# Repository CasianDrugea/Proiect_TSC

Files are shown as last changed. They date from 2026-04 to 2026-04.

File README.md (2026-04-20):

# Documentație Tehnică - InkTime Smartwatch
## Student: Drugea Casian 332CA

## 1. Descrierea Generală a Sistemului
Proiectul **InkTime** este un dispozitiv purtabil bazat pe microcontrolerul **nRF52840**, proiectat pentru a oferi o autonomie ridicată prin utilizarea unui ecran de tip E-Paper. Sistemul integrează funcționalități de monitorizare a mișcării, interfață haptică și un management avansat al energiei, fiind optimizat pentru dimensiuni reduse și eficiență.

## 2. Diagrama Bloc
Arhitectura hardware este structurată în jurul nucleului ARM Cortex-M4F, interconectat cu următoarele module:

* **Sistem de Procesare:** nRF52840 (Bluetooth 5.0, GPIO, SPI, I2C).
* **Afișaj:** E-Paper Display (EPD) cu circuit de drive integrat.
* **Senzori & Haptics:** Accelerometru BMA423 și Driver Haptic DRV2605.
* **Management Energie:** Încărcător LiPo BQ25180, Fuel Gauge MAX17048 și convertor DC/DC RT610A.
* **Interfață Utilizator:** Trei butoane de control (Up, Enter, Down).

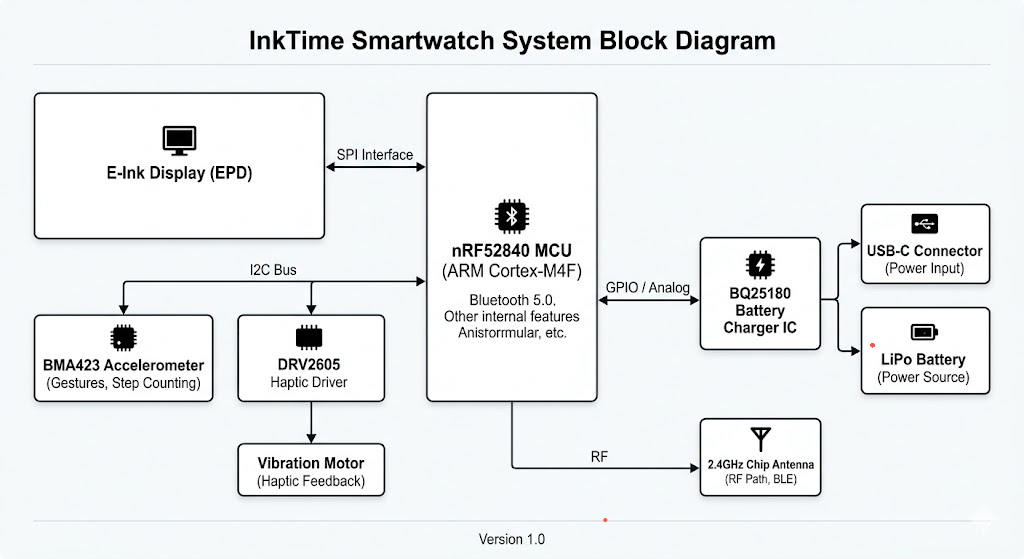
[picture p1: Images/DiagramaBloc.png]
Diagrama Bloc InkTime


## 3. Funcționalitate Hardware și Interfețe
Dispozitivul utilizează următoarele soluții tehnice pentru realizarea funcțiilor sale:

* **Microcontroler (nRF52840):** Gestionează stiva de comunicație Bluetooth și coordonează toți perifericii. S-a optat pentru acest model datorită consumului redus în modurile de repaus și a unității de calcul în virgulă mobila (FPU).
* **Afișaj E-Paper:** Este controlat prin interfața **SPI**. Circuitul de drive (bazat pe inductorul L5 și diodele MBR0530) asigură tensiunile necesare pentru actualizarea pixelilor.
* **Managementul Bateriei:**
    * **BQ25180:** Gestionează încărcarea prin USB-C și monitorizează curentul de intrare.
    * **MAX17048:** Monitorizează tensiunea celulei LiPo și oferă un algoritm de calcul al stării de încărcare (SoC) prin I2C.
    * **RT610A:** Un convertor Buck-Boost care stabilizează tensiunea la 3.3V, indiferent de nivelul de descărcare al bateriei.
* **Senzori și Actuatori:**
    * **BMA423:** Senzor de mișcare conectat prin I2C, utilizat pentru pedometru și gesturi.
    * **DRV2605:** Driver pentru motorul de vibrații, capabil să redea efecte haptice complexe.
* **Protecție și RF:** Linia USB-C este protejată de descărcări electrostatice prin **USBLC6-2SC6Y**. Antena ceramică de 2.4GHz este acordată prin componentele de matching (L4, C9) pentru o performanță optimă la 50 Ω.

## 4. Alocare Pini (Pinout nRF52840)

* **E-Paper (SPI):** `P0.14`, `P0.15`, `P0.17`, `P0.19`, `P0.20`, `P0.22` – Gestionează transferul datelor de imagine și semnalele de control (CS, BUSY, RES, DC).
* **I2C Bus (Shared):** `P0.26 (SDA)`, `P0.27 (SCL)` – Magistrală comună pentru senzorul IMU (BMA423), Fuel Gauge, Haptic Driver și Charger.
* **Butoane Fizice:** `P0.11`, `P0.12`, `P0.24` – Intrări digitale pentru butoanele de navigare UP, ENTER și DOWN.
* **Battery Charger:** `P0.02` – Pin de întrerupere (INT) pentru monitorizarea statusului de încărcare de la BQ25180.
* **Fuel Gauge:** `P0.03` – Linie de alertă pentru nivelul critic al bateriei de la MAX17048.
* **Crystal 32kHz:** `P0.00`, `P0.01` – Conexiuni dedicate XL1/XL2 pentru menținerea timpului în modurile Low Power.
* **Haptic Enable:** `P0.21` – Control GPIO pentru activarea driverului de vibrații DRV2605.
* **DC/DC Enable:** `P0.13` – Controlul regulatorului de tensiune pentru managementul energiei sistemului.
* **Debug Interface:** `SWDIO`, `SWDCLK` – Pini dedicați pentru programarea firmware-ului și depanare.
* **USB Native:** `D+`, `D-`, `VBUS` – Interfață pentru comunicație de date și detecția alimentării prin USB-C.

## 5. Fabricație și Fișiere de Producție
Dosarul proiectului include toate documentele necesare fabricării PCB-ului și asamblării (PCBA):

* **BOM (.bom):** Lista completă de componente cu link-uri către furnizori și coduri de comandă LCSC.
* **Gerber Files (.zip):** Straturile de cupru, masca de lipire, silkscreen-ul și fișierele de găurire (Drill).
* **Pick & Place (.cpl):** Coordonatele X-Y și rotația fiecărei componente pentru asamblarea automată.

## 6. Jurnal de Design și Decizii Tehnice
* **Utilizarea componentelor 0201:** Condensatorii de decuplare de sub nRF52840 sunt de mărime 0201 pentru a permite o rutare cât mai scurtă către masă și a economisi spațiu pe un PCB dens.
* **Traseele de alimentare și utilizarea VIA-urilor:** S-a optat pentru utilizarea trecerilor metalizate (vias) pe traseele de alimentare (V_BAT, 3.3V) pentru a facilita rutarea între straturi în zonele aglomerate. Justificarea tehnică rezidă în necesitatea de a menține o impedanță scăzută; în punctele de distribuție principală, s-au folosit mai multe via-uri în paralel pentru a crește capacitatea de transport a curentului și pentru a reduce inductanța parazită, prevenind astfel căderile de tensiune în timpul vârfurilor de consum (ex: refresh E-Ink sau transmisie RF).
* **Selecția Antenei:** S-a ales o antenă tip "Chip" pentru a reduce dimensiunea totală a carcasei, eliminând necesitatea unei antene imprimate pe PCB care ar fi ocupat o suprafață mai mare.
* **Erori de Suprapunere (Design Rule Check):** S-au ignorat erorile de suprapunere ale textului (silkscreen) în zonele critice ale conectorilor, prioritizând integritatea traseelor de semnal și a pad-urilor în detrimentul vizibilității etichetelor.

## 7. Structura Fișierelor
* `/Hardware`: Fișierele sursă `.sch` și `.brd`.
* `/Manufacturing`: Fișierele de producție (Gerber, BOM, CPL).
* `/Mechanical`: Modelul 3D al ansamblului complet (.step și .f3z).
* `/Images`: Randări ale dispozitivului și diagrame de sistem.

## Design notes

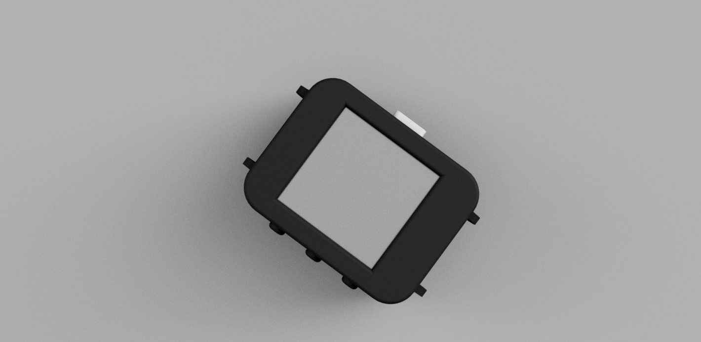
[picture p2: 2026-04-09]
Images/imag2.png

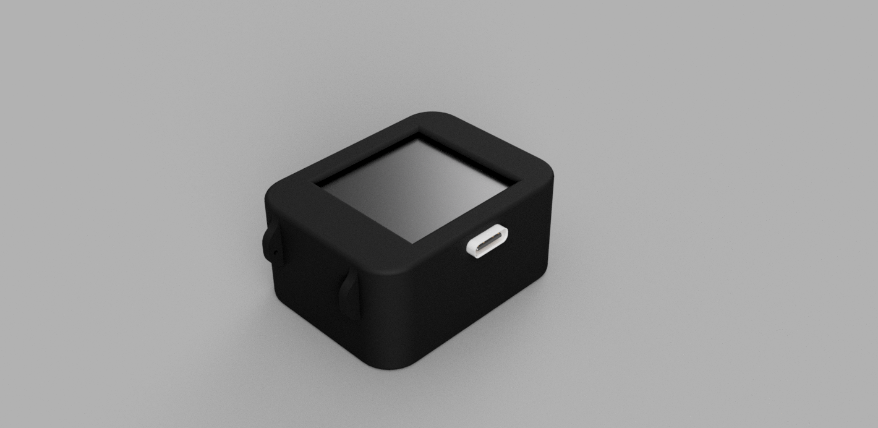
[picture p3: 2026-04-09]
Images/imag1.png

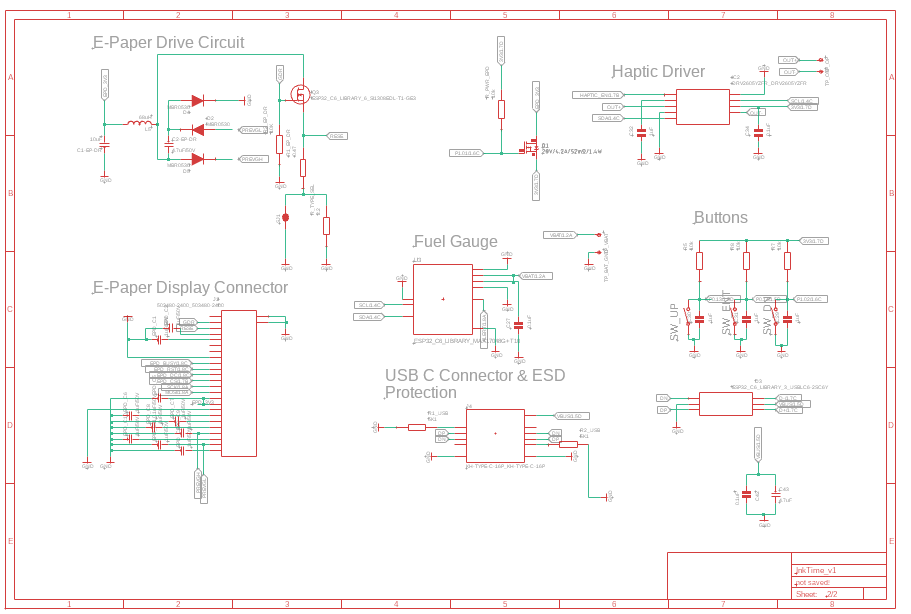
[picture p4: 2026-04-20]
Images/Sheet2.png

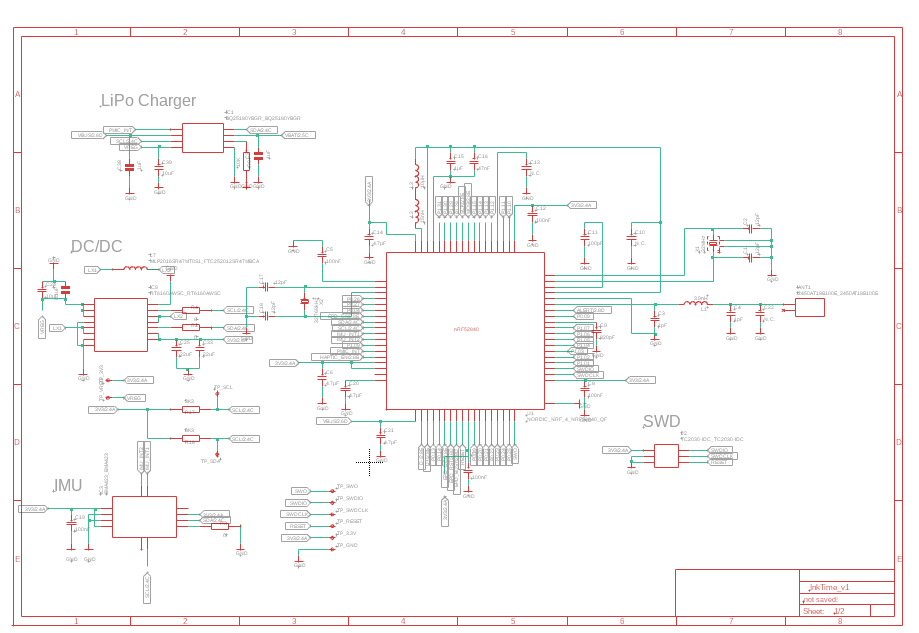
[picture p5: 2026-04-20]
Images/Sheet1.png

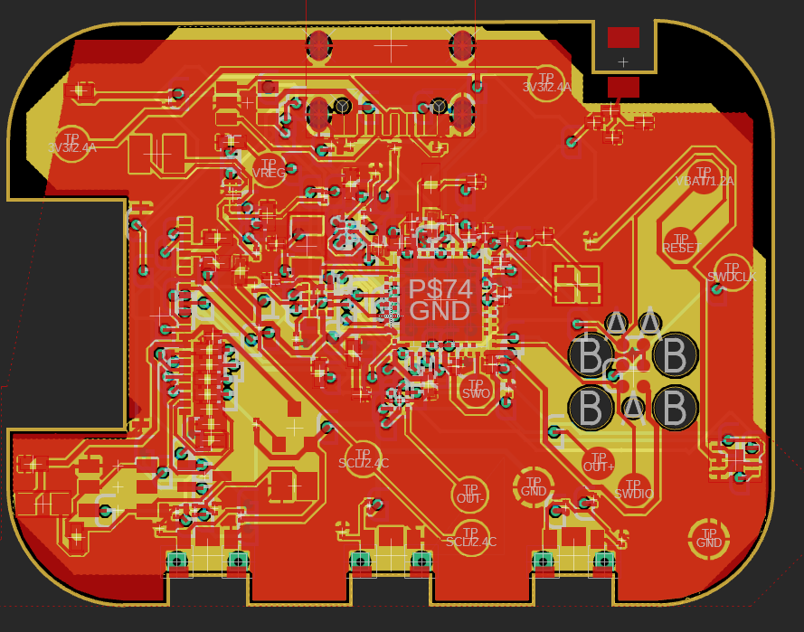
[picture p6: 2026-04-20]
Images/PCB.png

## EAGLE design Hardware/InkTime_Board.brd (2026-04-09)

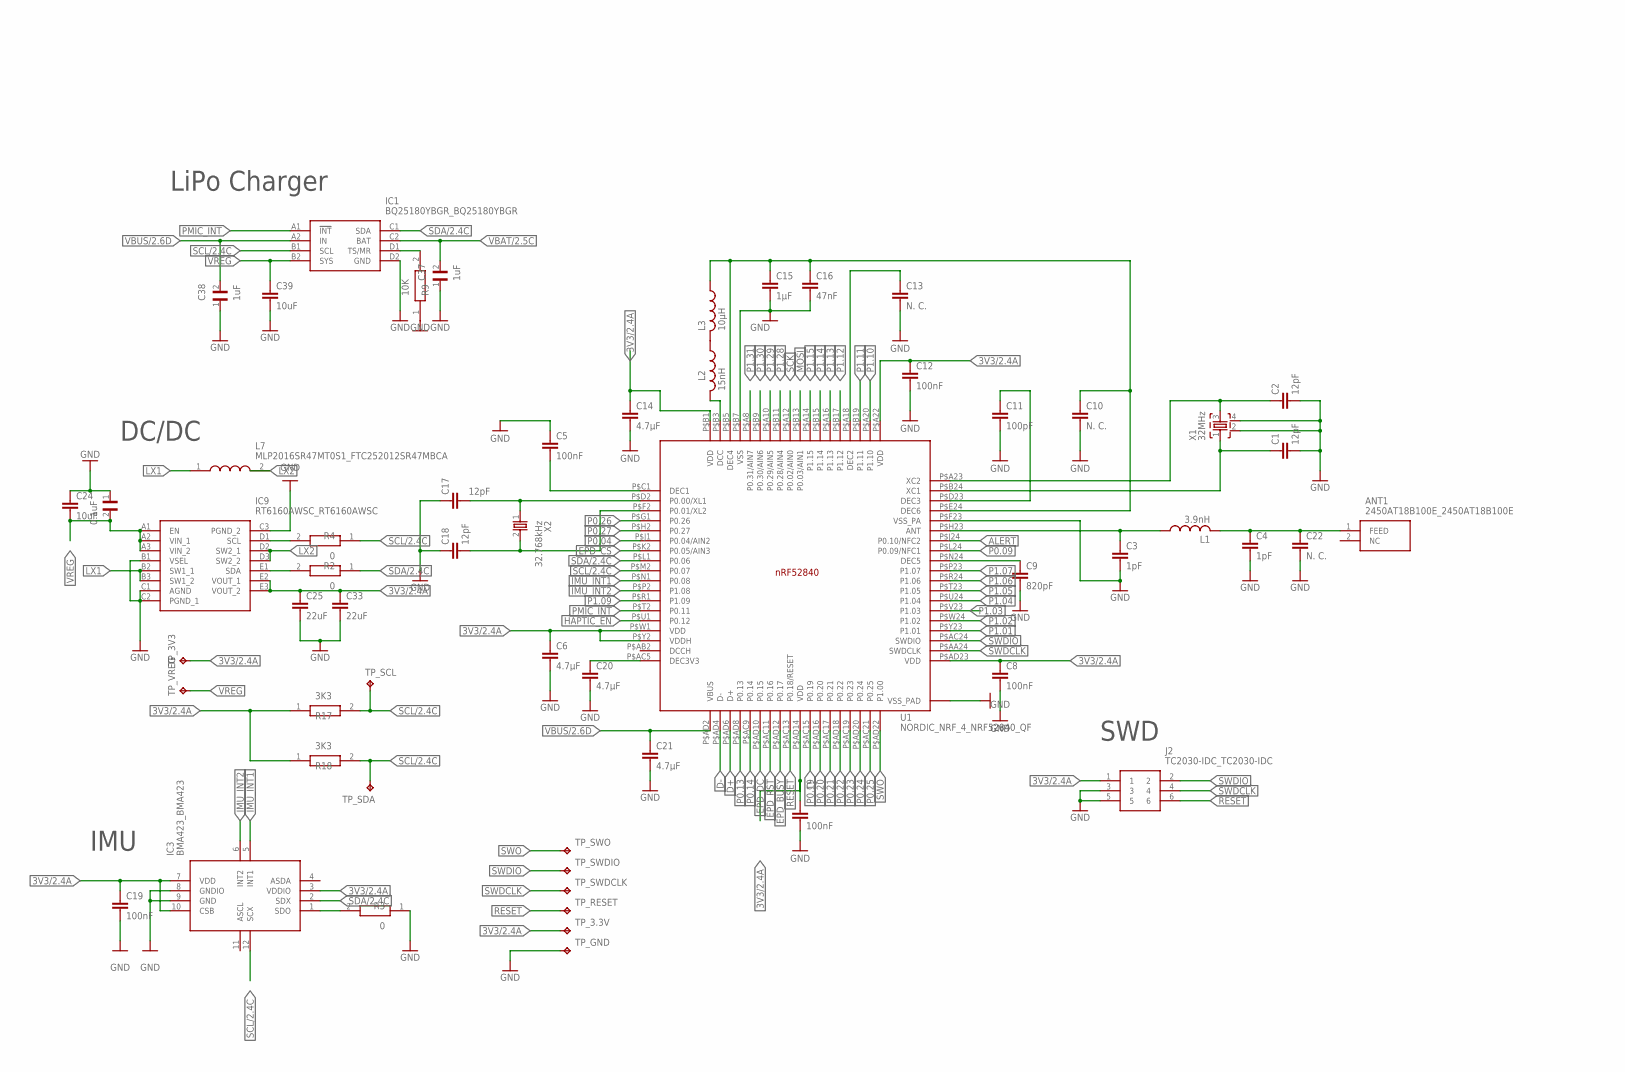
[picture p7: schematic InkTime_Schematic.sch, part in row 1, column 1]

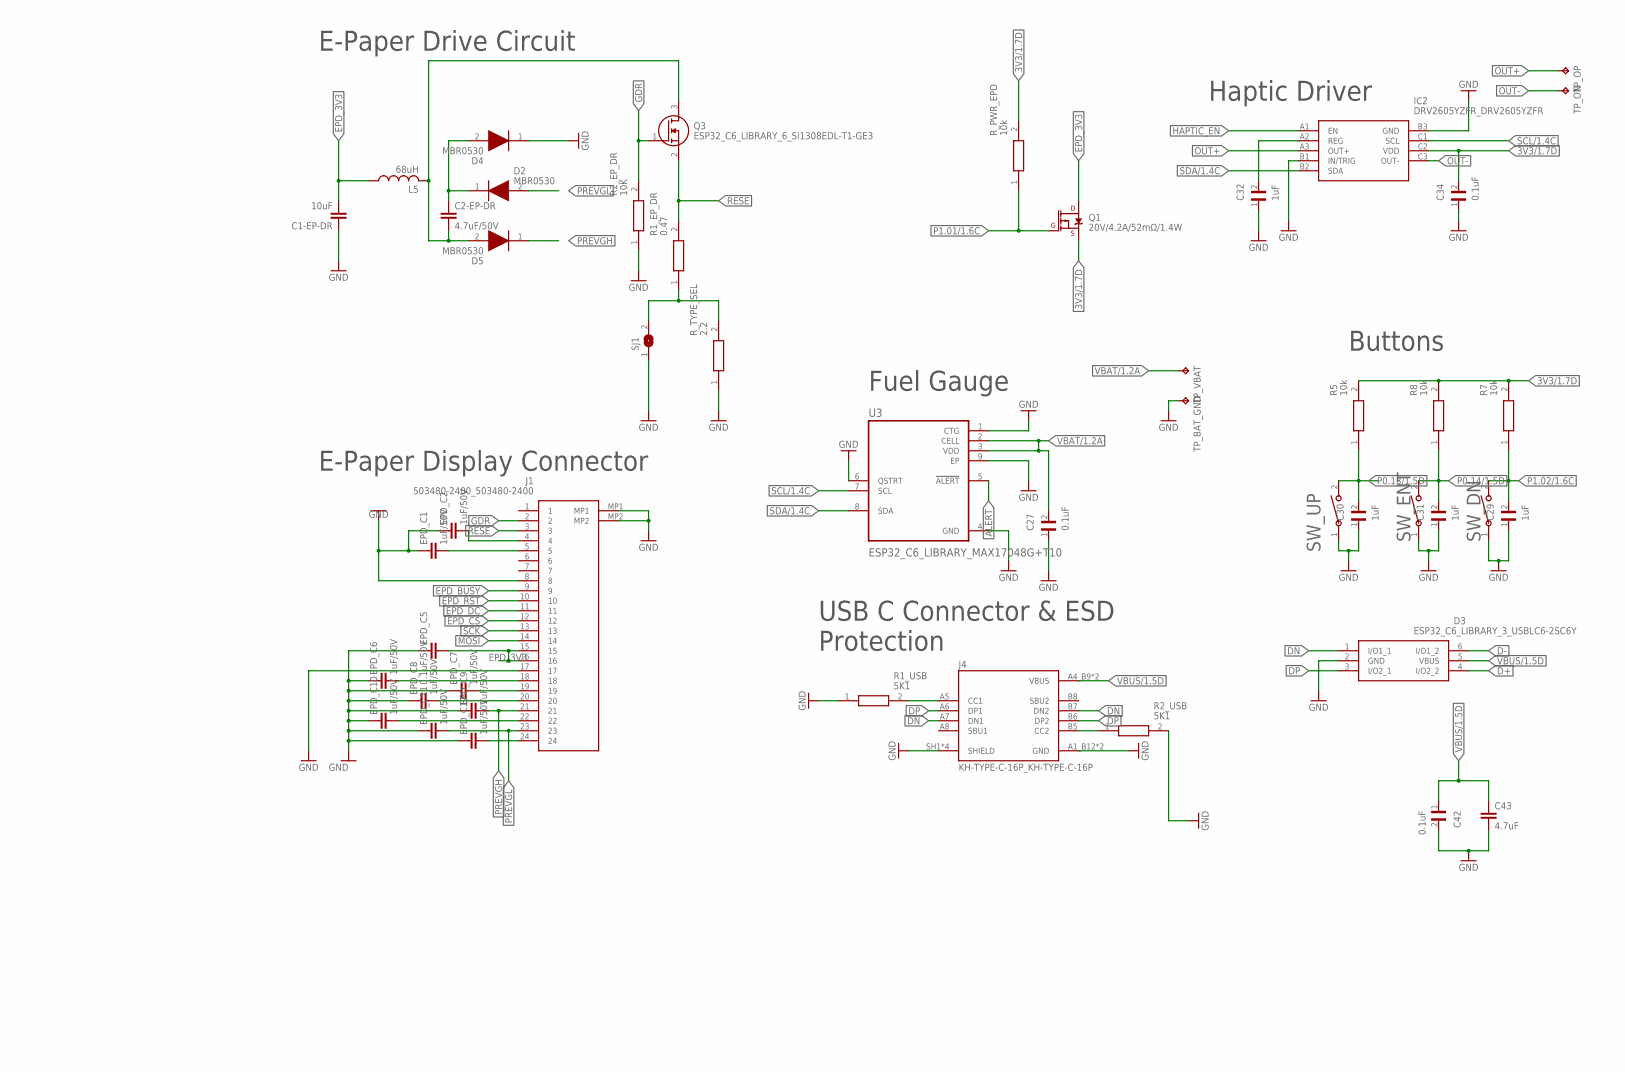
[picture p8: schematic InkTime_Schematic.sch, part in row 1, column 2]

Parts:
ANT1: 2450AT18B100E_2450AT18B100E; 2450AT18B100E_ANTC3216X140N
C1, C2, C17, C18: 12pF; NORDIC_NRF_3_RESC0201_L
C1-EP-DR, C24, C39: 10uF; NORDIC_NRF_3_RESC0402_L
C2-EP-DR: 4.7uF/50V; NORDIC_NRF_3_RESC0402_L
C3, C4: 1pF; NORDIC_NRF_3_RESC0201_L
C5, C7, C8, C12, C19: 100nF; NORDIC_NRF_3_RESC0201_L
C6, C14, C20, C21: 4.7µF; NORDIC_NRF_3_RESC0402_L
C9: 820pF; NORDIC_NRF_3_RESC0201_L
C10, C13, C22: N. C.; NORDIC_NRF_3_RESC0201_L
C11: 100pF; NORDIC_NRF_3_RESC0201_L
C15: 1µF; NORDIC_NRF_3_RESC0402_L
C16: 47nF; NORDIC_NRF_3_RESC0201_L
C23, C27, C34, C42: 0.1uF; GRM011R60J152KE01L_1_0201
C25, C33: 22uF; NORDIC_NRF_3_RESC0402_L
C29, C30, C31, C32, C37, C38: 1uF; GRM011R60J152KE01L_1_0201
C43: 4.7uF; NORDIC_NRF_3_RESC0402_L
D2, D4, D5: MBR0530; ESP32_C6_LIBRARY_5_SOD3716X135N
D3: ESP32_C6_LIBRARY_3_USBLC6-2SC6Y; ESP32_C6_LIBRARY_3_SOT95P280X145-6N
EPD_C1, EPD_C2, EPD_C6, EPD_C7, EPD_C8, EPD_C9, EPD_C10, EPD_C11, EPD_C12: 1uF/50V; NORDIC_NRF_3_RESC0402_L
EPD_C5: 0.1uF/50V; NORDIC_NRF_3_RESC0201_L
IC1: BQ25180YBGR_BQ25180YBGR; BQ25180YBGR_BGA8C40P2X4_100X155X50
IC2: DRV2605YZFR_DRV2605YZFR; DRV2605YZFR_BGA9C50P3X3_144X144X62
IC3: BMA423_BMA423
IC9: RT6160AWSC_RT6160AWSC; RT6160AWSC_BGA15C40P3X5_140X230X60
J1: 503480-2400_503480-2400; 503480-2400_5034802400
J2: TC2030-IDC_TC2030-IDC; TC2030-IDC_TC2030IDC
J4: KH-TYPE-C-16P_KH-TYPE-C-16P; KH-TYPE-C-16P_KINGHELM_KH-TYPE-C-16P
L1: 3.9nH; NORDIC_NRF_2_RESC0201_L
L2: 15nH; NORDIC_NRF_2_RESC0201_L
L3: 10µH; NORDIC_NRF_2_RESC0603_L
L5: 68uH; NORDIC_NRF_2_RESC0805_L
L7: MLP2016SR47MT0S1_FTC252012SR47MBCA; MLP2016SR47MT0S1_INDC2016X100N
Q1: 20V/4.2A/52mΩ/1.4W; ESP32_C6_LIBRARY_4_ESP32_C6_LIBRARY_4_ESP32_C6_LIBRARY_4_ES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
Q3: ESP32_C6_LIBRARY_6_SI1308EDL-T1-GE3; ESP32_C6_LIBRARY_6_SOT65P210X110-3N
R1_EP_DR: 0.47; ERA-1AEB3401C_0201
R1_USB, R2_USB: 5K1; ERA-1AEB3401C_0201
R2, R3, R4: 0; CPF0201D7K68C1_0201
R2_EP_DR: 10K; ERA-1AEB3401C_0201
R5, R7, R8: 10k; ERA-1AEB3401C_0201
R9: 10K; CPF0201D7K68C1_0201
R17, R18: 3K3; CPF0201D7K68C1_0201
R_PWR_EPD: 10k; ERA-1AEB3401C_0201
R_TYPE_SEL: 2.2; ERA-1AEB3401C_0201
SJ1: ESP32_C6_LIBRARY_7_JUMPER_SJ
SW_DN: 2025-10-22_07-23-44_LIBRARY_EVP-AKE31ASW_EVP-AKE3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; 2025-10-22_07-23-44_LIBRARY_SW_EVP-AKE31A_PAN
SW_ENT: 2025-10-22_07-23-44_LIBRARY_EVP-AKE31ASW_EVP-AKE3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; 2025-10-22_07-23-44_LIBRARY_SW_EVP-AKE31A_PAN
SW_UP: 2025-10-22_07-23-44_LIBRARY_EVP-AKE31ASW_EVP-AKE3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; 2025-10-22_07-23-44_LIBRARY_SW_EVP-AKE31A_PAN
TP_3.3V, TP_3V3: HECTOR_WATCH_1_TPTP20R; HECTOR_WATCH_1_TP20R
TP_BAT_GND: HECTOR_WATCH_1_TPTP20R; HECTOR_WATCH_1_TP20R
TP_GND: HECTOR_WATCH_1_TPTP20R; HECTOR_WATCH_1_TP20R
TP_ON: HECTOR_WATCH_1_TPTP20R; HECTOR_WATCH_1_TP20R
TP_OP: HECTOR_WATCH_1_TPTP20R; HECTOR_WATCH_1_TP20R
TP_RESET: HECTOR_WATCH_1_TPTP20R; HECTOR_WATCH_1_TP20R
TP_SCL: HECTOR_WATCH_1_TPTP20R; HECTOR_WATCH_1_TP20R
TP_SDA: HECTOR_WATCH_1_TPTP20R; HECTOR_WATCH_1_TP20R
TP_SWDCLK: HECTOR_WATCH_1_TPTP20R; HECTOR_WATCH_1_TP20R
TP_SWDIO: HECTOR_WATCH_1_TPTP20R; HECTOR_WATCH_1_TP20R
TP_SWO: HECTOR_WATCH_1_TPTP20R; HECTOR_WATCH_1_TP20R
TP_VBAT: HECTOR_WATCH_1_TPTP20R; HECTOR_WATCH_1_TP20R
TP_VREG: HECTOR_WATCH_1_TPTP20R; HECTOR_WATCH_1_TP20R
U1: NORDIC_NRF_4_NRF52840_QF; NORDIC_NRF_4_AQFN50P700X700X85_HS-74N
U3: ESP32_C6_LIBRARY_MAX17048G+T10; ESP32_C6_LIBRARY_SON50P200X200X80-9N
X1: 32MHz; NORDIC_NRF_BT-XTAL_2016_N
X2: 32.768kHz; NORDIC_NRF_1_XTAL_3215_N

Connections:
3V3/1.7D: C34.2, IC2.C2 (VDD), Q1.2 (S), R5.2, R7.2, R8.2, R_PWR_EPD.2
3V3/2.4A: C6.1, C7.1, C8.1, C12.1, C14.1, C19.1, C25.1, C33.1, IC3.3 (VDDIO), IC3.7 (VDD), IC3.10 (CSB), IC9.E2 (VOUT_1), IC9.E3 (VOUT_2), J2.1, R17.1, R18.1, TP_3.3V.TP, TP_3V3.TP, U1.P$A22 (VDD), U1.P$AD14 (VDD), U1.P$AD23 (VDD), U1.P$B1 (VDD), U1.P$W1 (VDD), U1.P$Y2 (VDDH)
ALERT: U1.P$J24 (P0.10/NFC2), U3.5 (!ALERT)
D+: D3.4 (I/O2_2), U1.P$AD6 (D+)
D-: D3.6 (I/O1_2), U1.P$AD4 (D-)
DN: D3.1 (I/O1_1), J4.A7 (DN1), J4.B7 (DN2)
DP: D3.3 (I/O2_1), J4.A6 (DP1), J4.B6 (DP2)
EPD_3V3: C1-EP-DR.2, EPD_C5.2, J1.15, J1.16, L5.1, Q1.3 (D)
EPD_BUSY: J1.9, U1.P$AD12 (P0.17)
EPD_CS: J1.12, U1.P$K2 (P0.05/AIN3)
EPD_DC: J1.11, U1.P$AD10 (P0.15)
EPD_RST: J1.10, U1.P$AC11 (P0.16)
GDR: J1.2, Q3.1 (G), R2_EP_DR.2
GND: C1.2, C1-EP-DR.1, C2.2, C3.2, C4.2, C5.1, C6.2, C7.2, C8.2, C9.2, C10.2, C11.2, C12.2, C13.2, C14.2, C15.2, C16.2, C17.1, C18.1, C19.2, C20.2, C21.2, C22.2, C23.1, C24.1, C25.2, C27.1, C29.1, C30.1, C31.1, C32.1, C33.2, C34.1, C37.1, C38.1, C39.2, C42.2, C43.2, D3.2 (GND), D4.1 (K), EPD_C1.1, EPD_C2.1, EPD_C5.1, EPD_C6.1, EPD_C7.1, EPD_C8.1, EPD_C9.1, EPD_C10.1, EPD_C11.1, EPD_C12.1, IC1.D2 (GND), IC2.B1 (IN/TRIG), IC2.B3 (GND), IC3.8 (GNDIO), IC3.9 (GND), IC9.B1 (VSEL), IC9.C1 (AGND), IC9.C2 (PGND_1), IC9.C3 (PGND_2), J1.8, J1.17, J1.MP1, J1.MP2, J2.3, J2.5, J4.A1_B12 (GND), J4.A12_B1 (GND), J4.SH1 (SHIELD), J4.SH2 (SHIELD), J4.SH3 (SHIELD), J4.SH4 (SHIELD), R1_USB.1, R2_EP_DR.1, R2_USB.2, R3.1, R9.1, R_TYPE_SEL.1, SJ1.1, SW_DN.1, SW_ENT.1, SW_UP.1, TP_BAT_GND.TP, TP_GND.TP, U1.P$74 (VSS_PAD), U1.P$75 (VSS_PAD), U1.P$76 (VSS_PAD), U1.P$77 (VSS_PAD), U1.P$78 (VSS_PAD), U1.P$79 (VSS_PAD), U1.P$80 (VSS_PAD), U1.P$81 (VSS_PAD), U1.P$82 (VSS_PAD), U1.P$83 (VSS_PAD), U1.P$84 (VSS_PAD), U1.P$85 (VSS_PAD), U1.P$86 (VSS_PAD), U1.P$87 (VSS_PAD), U1.P$88 (VSS_PAD), U1.P$89 (VSS_PAD), U1.P$90 (VSS_PAD), U1.P$B7 (VSS), U1.P$F23 (VSS_PA), U3.1 (CTG), U3.4 (GND), U3.6 (QSTRT), U3.9 (EP), X1.2, X1.4
HAPTIC_EN: IC2.A1 (EN), U1.P$U1 (P0.12)
IMU_INT1: IC3.5 (INT1), U1.P$N1 (P0.08)
IMU_INT2: IC3.6 (INT2), U1.P$P2 (P1.08)
LX1: IC9.B2 (SW1_1), IC9.B3 (SW1_2), L7.1
LX2: IC9.D2 (SW2_1), IC9.D3 (SW2_2), L7.2
MOSI: J1.14, U1.P$B13 (P0.03/AIN1)
unnamed: C5.2, U1.P$C1 (DEC1)
unnamed: L2.2, U1.P$B3 (DCC)
unnamed: L2.1, L3.2
unnamed: C2.1, U1.P$A23 (XC2), X1.3
unnamed: C20.1, U1.P$AC5 (DEC3V3)
unnamed: C9.1, U1.P$N24 (DEC5)
unnamed: C11.1, U1.P$D23 (DEC3)
unnamed: C13.1, U1.P$A18 (DEC2)
unnamed: C3.1, L1.1, U1.P$H23 (ANT)
unnamed: C10.1, C15.1, C16.1, L3.1, U1.P$B5 (DEC4), U1.P$E24 (DEC6)
unnamed: ANT1.1 (FEED), C4.1, C22.1, L1.2
unnamed: C1.1, U1.P$B24 (XC1), X1.1
unnamed: C17.2, U1.P$D2 (P0.00/XL1), X2.1
unnamed: C18.2, U1.P$F2 (P0.01/XL2), X2.2
unnamed: IC1.D1 (TS/MR), R9.2
unnamed: IC9.E1 (SDA), R2.2
unnamed: IC9.D1 (SCL), R4.2
unnamed: IC3.1 (SDO), R3.2
unnamed: C32.2, IC2.A2 (REG)
unnamed: J4.A5 (CC1), R1_USB.2
unnamed: J4.B5 (CC2), R2_USB.1
unnamed: EPD_C2.2, J1.4
unnamed: EPD_C1.2, J1.5
unnamed: EPD_C6.2, J1.18
unnamed: EPD_C7.2, J1.19
unnamed: EPD_C8.2, J1.20
unnamed: EPD_C10.2, J1.22
unnamed: EPD_C12.2, J1.24
unnamed: C2-EP-DR.2, D5.2 (A), L5.2, Q3.3 (D)
unnamed: C2-EP-DR.1, D2.1 (K), D4.2 (A)
unnamed: R1_EP_DR.1, R_TYPE_SEL.2, SJ1.2
OUT+: IC2.A3 (OUT+), TP_OP.TP
OUT-: IC2.C3 (OUT-), TP_ON.TP
P0.04: U1.P$J1 (P0.04/AIN2)
P0.09: U1.P$L24 (P0.09/NFC1)
P0.13: U1.P$AD8 (P0.13)
P0.13/1.5D: C30.2, R5.1, SW_UP.2
P0.14: U1.P$AC9 (P0.14)
P0.14/1.5D: C31.2, R8.1, SW_ENT.2
P0.19: U1.P$AC15 (P0.19)
P0.20: U1.P$AD16 (P0.20)
P0.21: U1.P$AC17 (P0.21)
P0.22: U1.P$AD18 (P0.22)
P0.23: U1.P$AC19 (P0.23)
P0.24: U1.P$AD20 (P0.24)
P0.25: U1.P$AC21 (P0.25)
P0.26: U1.P$G1 (P0.26)
P0.27: U1.P$H2 (P0.27)
P1.01: U1.P$Y23 (P1.01)
P1.01/1.6C: Q1.1 (G), R_PWR_EPD.1
P1.02: U1.P$W24 (P1.02)
P1.02/1.6C: C29.2, R7.1, SW_DN.2
P1.03: U1.P$V23 (P1.03)
P1.04: U1.P$U24 (P1.04)
P1.05: U1.P$T23 (P1.05)
P1.06: U1.P$R24 (P1.06)
P1.07: U1.P$P23 (P1.07)
P1.09: U1.P$R1 (P1.09)
P1.10: U1.P$A20 (P1.10)
P1.11: U1.P$B19 (P1.11)
P1.12: U1.P$B17 (P1.12)
P1.13: U1.P$A16 (P1.13)
P1.14: U1.P$B15 (P1.14)
P1.15: U1.P$A14 (P1.15)
P1.28: U1.P$B11 (P0.28/AIN4)
P1.29: U1.P$A10 (P0.29/AIN5)
P1.30: U1.P$B9 (P0.30/AIN6)
P1.31: U1.P$A8 (P0.31/AIN7)
PMIC_INT: IC1.A1 (!INT), U1.P$T2 (P0.11)
PREVGH: D5.1 (K), EPD_C9.2, J1.21
PREVGL: D2.2 (A), EPD_C11.2, J1.23
RESE: J1.3, Q3.2 (S), R1_EP_DR.2
RESET: J2.6, TP_RESET.TP, U1.P$AC13 (P0.18/RESET)
SCK: J1.13, U1.P$A12 (P0.02/AIN0)
SCL/1.4C: IC2.C1 (SCL), U3.7 (SCL)
SCL/2.4C: IC1.B1 (SCL), IC3.12 (SCX), R4.1, R17.2, R18.2, TP_SCL.TP, TP_SDA.TP, U1.P$M2 (P0.07)
SDA/1.4C: IC2.B2 (SDA), U3.8 (SDA)
SDA/2.4C: IC1.C1 (SDA), IC3.2 (SDX), R2.1, U1.P$L1 (P0.06)
SWDCLK: J2.4, TP_SWDCLK.TP, U1.P$AA24 (SWDCLK)
SWDIO: J2.2, TP_SWDIO.TP, U1.P$AC24 (SWDIO)
SWO: TP_SWO.TP, U1.P$AD22 (P1.00)
VBAT/1.2A: C27.2, TP_VBAT.TP, U3.2 (CELL), U3.3 (VDD)
VBAT/2.5C: C37.2, IC1.C2 (BAT)
VBUS/1.5D: C42.1, C43.1, D3.5 (VBUS), J4.A4_B9 (VBUS), J4.A9_B4 (VBUS)
VBUS/2.6D: C21.1, C38.2, IC1.A2 (IN), U1.P$AD2 (VBUS)
VREG: C23.2, C24.2, C39.1, IC1.B2 (SYS), IC9.A1 (EN), IC9.A2 (VIN_1), IC9.A3 (VIN_2), TP_VREG.TP

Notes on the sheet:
LiPo Charger
DC/DC
IMU
SWD
E-Paper Display Connector
E-Paper Drive Circuit
Haptic Driver
Fuel Gauge
USB C Connector & ESD Protection
Buttons

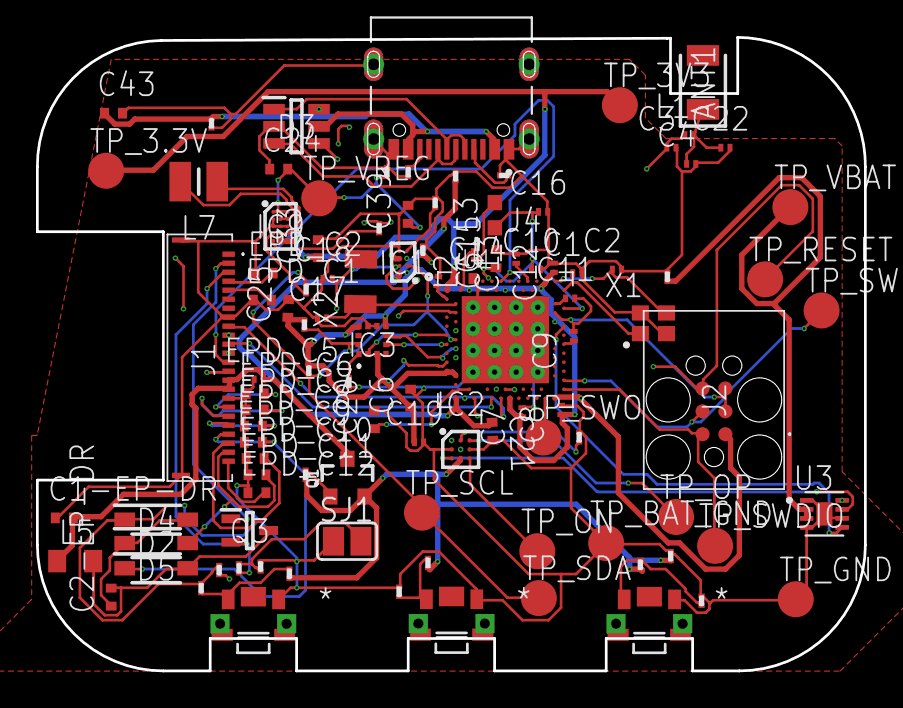
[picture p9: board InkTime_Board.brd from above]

Board: 4 copper layers, 46.0 x 35.2 mm, 105 parts (0 on the bottom side), 75 nets.

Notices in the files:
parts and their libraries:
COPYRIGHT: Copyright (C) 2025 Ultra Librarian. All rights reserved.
